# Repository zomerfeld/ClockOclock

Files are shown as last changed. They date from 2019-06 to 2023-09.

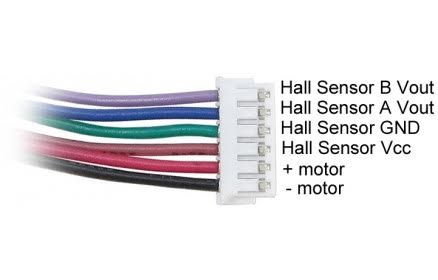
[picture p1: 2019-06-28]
Process_Pics_and_Docs/GearedMotorWiring.jpg

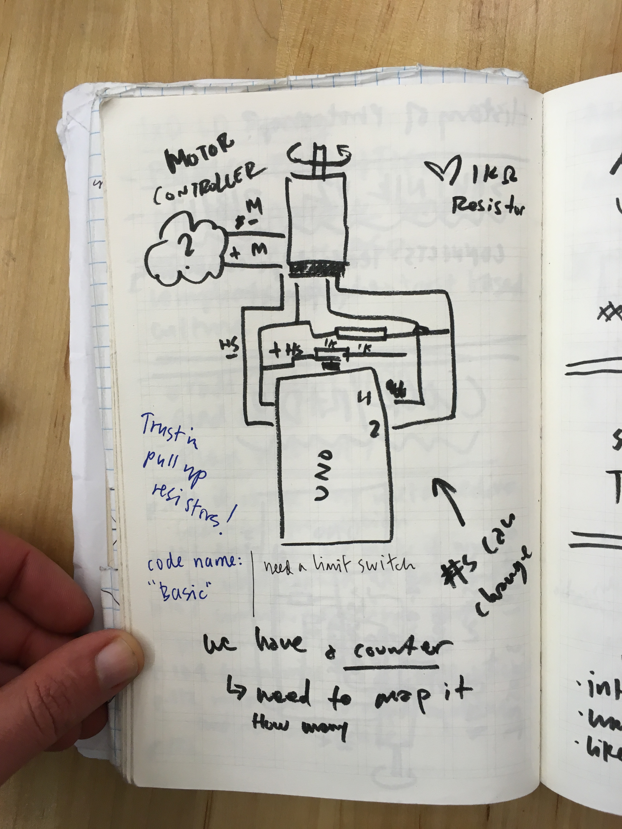
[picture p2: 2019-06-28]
Process_Pics_and_Docs/IMG_1472.JPG

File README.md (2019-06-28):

# ClockOclock
Rachel's Clock Project

## USAGE

### BOOTUP SEQUENCE
* When the radio boots up (or when serial opens) it goes through a calibration sequence:
  * It goes back to try to find the minimum point (it uses magnets and a hall sensor as a limit switch)
  * Then it goes forward to find the max point
  * Then it goes to a predetermined location (currently 90°)
* The board will then map the minimum point to 10 and the max point to 170 (temp values). You can now request it to go to specific angles based on that mapping. 

### MANUAL CONTROL
The board has two physical buttons that will move the motors back and forward. In addition to that, you can also move the dial with the 
* You can also control it via a serial connection, baud rate 250000
#### Commands
* **_\<any number\>_** - after the bootup sequence, this number will work as an angle for the front dial. 
  * Do not put any number lower than 10 or higher than 170 or the motor will try to take it there by force. 
* **_reset_** - runs the calibration sequence again and finds the endges 
* **_f_** - moves the motor forward a bit
* **_b_** - moves the motor backwards a bit

### Alarms
The board is currently set to run two functions on a schedule:
* the function _showTime_ every 5 seconds 
* the function _move90fm_ on a specific time

You can add timers or move the scheduled times under the section "Test Alarms" in the Setup function:
```
  Alarm.alarmRepeat(15, 52, 0, move90fm);
  Alarm.timerRepeat(5, showTime); // show time every 5 seconds

  moveSecAl = Alarm.timerRepeat(6, moveSec); // move every 6 seconds -- disabled currently 
```

## FAQ / TROUBLESHOOTING
#### Wanted ot change the max and min Values?
Change these:
```
int minAngle = 10; // Maximum degree of motion.
int maxAngle = 170; // Maximum degree of motion.
```

## THINGS THAT NEED REWORK
* Mapping isn't accurate (10-170 might need to be adjusted) 
* The board doesn't tell the difference between max and min limit switches currently
* The values for the hall sensor limit switch might need adjusting when you move the radio around to more or less magnetically noise environments.

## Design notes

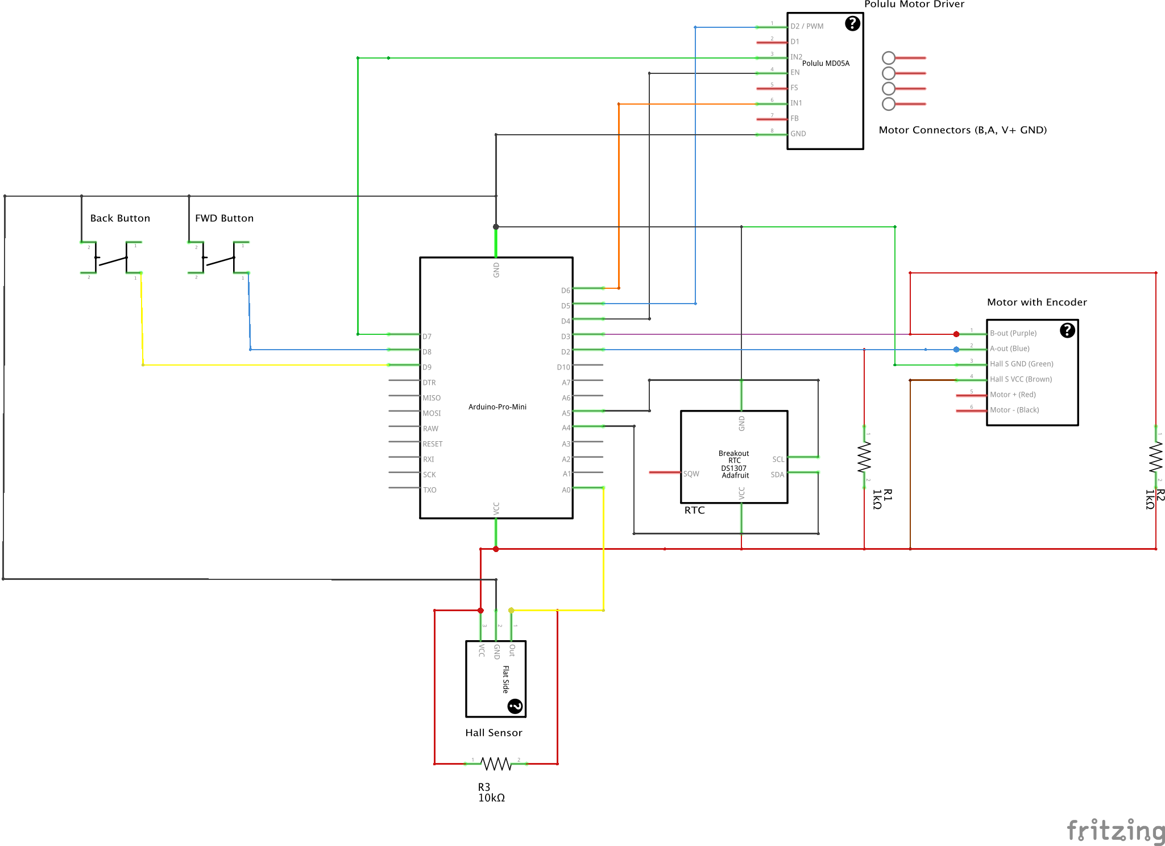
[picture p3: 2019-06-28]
Schematics/clock_oclock_v2_schem.png

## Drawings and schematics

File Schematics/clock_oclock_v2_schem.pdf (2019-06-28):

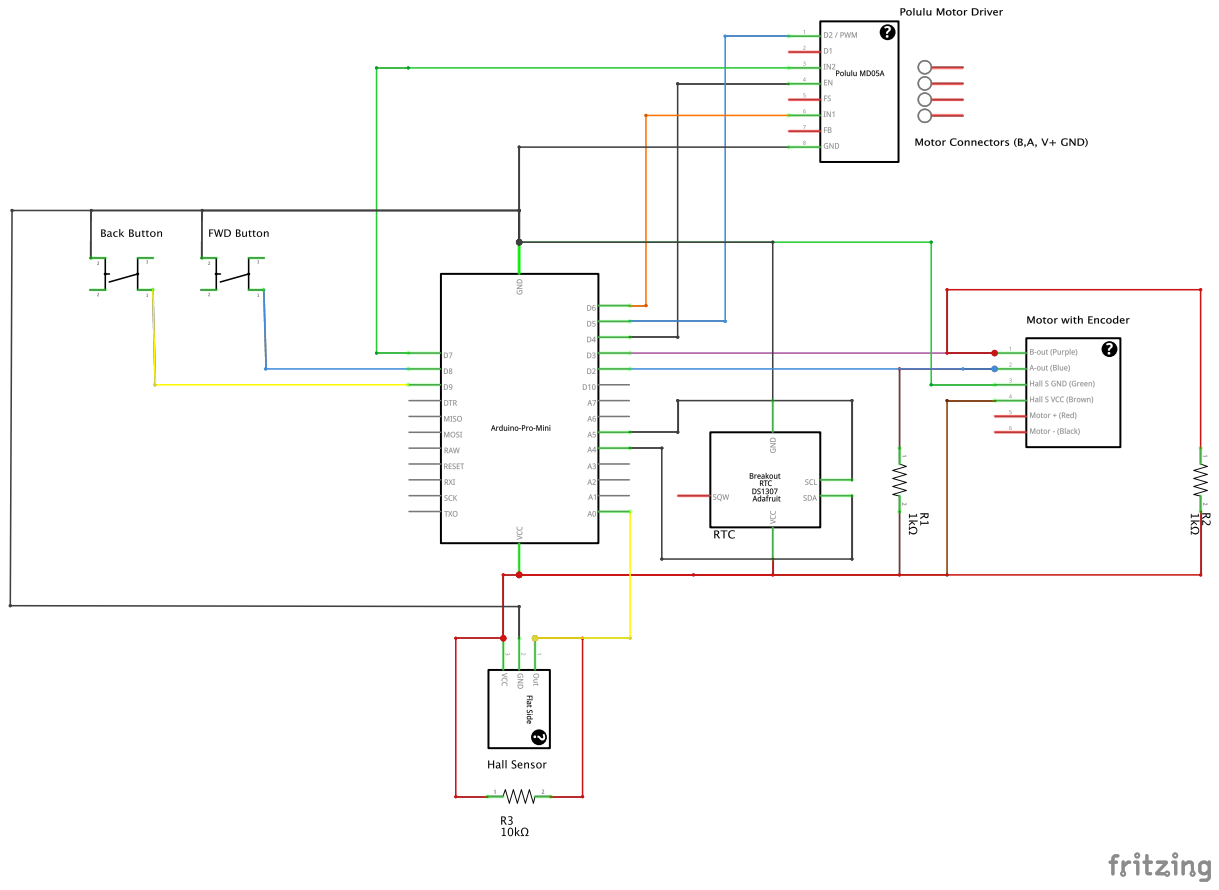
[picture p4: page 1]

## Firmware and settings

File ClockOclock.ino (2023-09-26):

// ***** Timer *****
unsigned long previousMillis = 0;        // will store last time LED was updated
const long printInterval = 5000;           // interval at which to print (milliseconds)


// ***** PID *****
#include <PID_v1.h>

// ***** RTC *****
#include <TimeLib.h>
#include <TimeAlarms.h>
#include <DS1307RTC.h>  // a basic DS1307 library that returns time as a time_t
//#include "RTClib.h"
//RTC_DS1307 rtc;
const char *monthName[12] = {
  "Jan", "Feb", "Mar", "Apr", "May", "Jun",
  "Jul", "Aug", "Sep", "Oct", "Nov", "Dec"
};

tmElements_t tm;


// RTC Wiring: 5V to 5V, GND to GND, SCL to A5 (on Uno, changes by controller), SDA to A4 (on Uno)
// TC Wiring: https://screencast.com/t/50Cv0fAUM7w5

#include <Bounce2.h>
// Initiate a Bounce object: //needed for digital switch
Bounce debouncer1 = Bounce();
Bounce debouncer2 = Bounce();


// *** PID VALUES ***
double kp = 10 , ki = 14 , kd =  0.001;             // modify for optimal performance
double input = 0, output = 0, setpoint = 0;
PID myPID(&input, &output, &setpoint, kp, ki, kd, DIRECT);

// *** MOTOR CONTROL PINS ***
#define enablePin 4 // Connect to EN - Send High or Low to enabled and disable the motor
#define motorSpeedPin 5 // Connect to D2 on the Pololu MD05A (Needs to be PWM pin)
#define CWPin 6 // Connect to IN1 - Turning HIGH will change the motor direction to ClockWise
#define CCWPin 7 // Connect to IN2 - Turning HIGH will change the motor direction to Counter ClockWise
// (flip the A/B wires if the direction is reversed)

#define fwdButton 8 //Button to move motor forward
#define backButton 9 //Button to move motor backward
#define debugLED 13 // Debug LED


// *** LIMIT SWITCH  ***
#define limitSwPin A0 // The pin for the limit switch.  
// For a regular switch, set as INPUT_PULLUP and connect the switch to GND and look for LOW for trigger. (https://www.arduino.cc/en/Tutorial/DigitalInputPullup)
int magnetHigh = 530; // It will only move if between these values!
int magnetLow = 499;


// *** SERIAL VARIABLES ***
String readString; //This while store the user input data
int User_Input = 0; // This while convert input string into integer
boolean stringComplete = false;  // whether the string is complete

// *** CLOCK VARIABLES ***
bool motorDisabled = 0; //To disable the motor passed limits
long maxPosition = 25L * 40000L;
long minPosition = 25L * 40000L;


//long cmdPosition = 200; // Where we're aiming the motor to go
bool motionDone = 1; // If the clock's in motion or not
long distanceMinute = 18; // CHANGE - How much we need to move for one minute passing - in angles
long distance5Second = 5; // CHANGE - How much we need to move for 5 seconds passing - in angles

// *** ENCODER VARIABLES ***
int encoderPin1 = 3; //Encoder Output 'A' must connected with intreput pin of arduino.
int encoderPin2 = 2; //Encoder Otput 'B' must connected with intreput pin of arduino.
//         Best Performance: both pins have interrupt capability
//         Good Performance: only the first pin has interrupt capability
//         Low Performance:  neither pin has interrupt capability
//         Make sure to pull UP those pins up with a 1K resistor (though the code seems to use the INPUT_PULLUP)
volatile int lastEncoded = 0; // Here updated value of encoder store.
volatile long encoderValue = 0; // Raw encoder value
int PPR = 7124;  // Encoder Pulse per revolution.
int minAngle = 12; // degrees to map with magents
int maxAngle = 170; // degrees to map with magnets
int destAngle = 0;
int REV = 0;          // Set point REQUIRED ENCODER VALUE
int lastMSB = 0;
int lastLSB = 0;

int maxGap = 20; // how much tolerance for overshoot or undershoot to say "good enough" and STOP motor. 20 seems a good value.

//these are  storage containers for messaging
long oldPosition  = -999;
long newPosition;


// *** ALARM / SECOND VARIABLES ***
// make this edit to TimeAlarms.h
// #define dtNBR_ALARMS 24  // max is 255
AlarmId id;
bool incrementalToggle = false;

int secondSpeed = 95; //the speed to move when moving once per second
int secondAngle = 1; // the angle-per-move change when moving once a second


// ************************************************************************************************************************************************







// ************************** SETUP **************************

void setup() {

  // ***** STARTS SERIAL & RTC *****
  Serial.begin(250000);
  Serial.println("Rachel's Clock");
  Serial.println("***STARTING RTC***");
  setSyncProvider(RTC.get);   // the function to get the time from the RTC
  setSyncInterval(8000);         // set the number of seconds between re-sync
  readString.reserve(200);   // reserve 200 bytes for the readString

  // *** Set time on RTC ***
  // These lines sets the RTC with an explicit date & time,
//  setTime(23,58,20,9,25,2023); //setTime(hr,min,sec,day,month,yr);
//  RTC.set(now());
  bool parse=false;
  bool config=false;
//
//  // get the date and time the compiler was run
//  if (getDate(__DATE__) && getTime(__TIME__)) {
//    parse = true;
//    // and configure the RTC with this info
//    if (RTC.write(tm)) {
//      config = true;
//    }
//  }


  // ***** PIN SETUP *****
  pinMode(enablePin, OUTPUT);
  pinMode(motorSpeedPin, OUTPUT);
  pinMode(CWPin, OUTPUT);
  pinMode(CCWPin, OUTPUT);
  pinMode(encoderPin1, INPUT_PULLUP);
  pinMode(encoderPin2, INPUT_PULLUP);
  pinMode(limitSwPin, INPUT);
  pinMode(enablePin, OUTPUT);
  pinMode(fwdButton, INPUT_PULLUP);
  pinMode(backButton, INPUT_PULLUP);
  pinMode(debugLED, OUTPUT);

  // encoder parameters
  digitalWrite(encoderPin1, HIGH); //turn pullup resistor on
  digitalWrite(encoderPin2, HIGH); //turn pullup resistor on
  // *** call updateEncoder() when any high/low changed seen
  //     on interrupt 0 (pin 2), or interrupt 1 (pin 3)
  attachInterrupt(0, updateEncoder, CHANGE);
  attachInterrupt(1, updateEncoder, CHANGE);
  REV = map (90, minAngle, maxAngle, minPosition, PPR); // mapping degree into pulse
  setpoint = REV;                    //Destination in revolutions - PID will work to achive this value consider as SET value      REV = map (User_Input, 10, angle, minPosition, PPR); // mapping degree into pulse

  TCCR1B = TCCR1B & 0b11111000 | 1;  // set 31KHz PWM to prevent motor noise

  // *** Setting PID ***
  myPID.SetMode(AUTOMATIC);   //set PID in Auto mode
  myPID.SetSampleTime(1);  // refresh rate of PID controller
  //  myPID.SetOutputLimits(-200, 200); // this is the MAX PWM value to move motor, here change in value reflect change in speed of motor.
  motorSpeed(200); // Sets Motor Speed // 70 is too slow

  // Buttons
  debouncer1.attach(fwdButton);
  debouncer2.attach(backButton);
  debouncer1.interval(90); // 90 seemed to work fast enough. Test and modify if needed
  debouncer2.interval(90); // 90 seemed to work fast enough. Test and modify if needed

  // If using Digital Limit Switch - , setup the Bounce instance (not needed for magnetic limit sw) :
  //  debouncer.attach(limitSwPin);
  //  debouncer.interval(90); // 90 seemed to work fast enough. Test and modify if needed

  // motor settings
  digitalWrite(enablePin, HIGH); // Turns the motor on
  findEdges(); // **** Start the find edges module ****


  // ***** Test Alarms *****
  //  Alarm.alarmRepeat(23,17,0, move90fm);
  //  Alarm.alarmRepeat(23,18,0, move100fm);
  //  Alarm.timerRepeat(5, showTime); // show time every 5 seconds

  //  moveSecAl = Alarm.timerRepeat(6, moveSec); // move every 6 seconds -- disabled currently

  // ****** FM ALARMS ******
  Alarm.alarmRepeat(20, 59, 58, move90fm) ;//should be (20, 59, 58, move90fm);
  Alarm.alarmRepeat(22, 00, 01, move100fm); //should be (22, 00, 01, move100fm)
  Alarm.alarmRepeat(23, 00, 00, moveRest);  //should be (23, 00, 00, moveRest)
  //
  // ****** AM ALARMS ******
  Alarm.alarmRepeat(5, 49, 58, move550am); // Should Be Alarm.alarmRepeat(5, 49, 58, move550am);
  Alarm.alarmRepeat(6, 0 , 0, move600am); // Should Be Alarm.alarmRepeat(6, 0, 0, move600am);
  Alarm.alarmRepeat(7, 0, 0, move700am); // Should Be Alarm.alarmRepeat(7, 0, 0, move700am);
  Alarm.alarmRepeat(8, 0, 0, move800am);  // Should Be Alarm.alarmRepeat(8, 0, 0, move800am);
  Alarm.alarmRepeat(9, 0, 0, move900am);// Should Be Alarm.alarmRepeat(9, 0, 0, move900am);
  Alarm.alarmRepeat(10, 0, 0, move1000am); // Should Be Alarm.alarmRepeat(10, 0, 0, move1000am);
  Alarm.alarmRepeat(11, 0, 0, move1100am); // Should Be Alarm.alarmRepeat(11, 0, 0, move1100am);
  Alarm.alarmRepeat(12, 0, 0, moveRest); // Should Be Alarm.alarmRepeat(12, 0, 0, moveRest);

  // NOT READY THERE MIGHT BE A MAX NUMBER OF ALARMS AND I HAVE TO FIGURE THAT OUT AND RELEASE SOME

}


// **********************************************************





// ************************** LOOP **************************

void loop() {
  // ***** UPDATE TIME *****
  unsigned long currentMillis = millis(); // all time elements are data type unsigned long
  Alarm.delay(0); // Needed to make the time library work.

  // *** Print Time ***
  if ((currentMillis - previousMillis) >= printInterval) { // enough time passed yet?
    previousMillis = currentMillis;
    showTime();
  }

  //  if (incrementalToggle == false) { // decide if to move incrementally (every second) or not
  //    Alarm.disable(moveSecAl);
  //  } else {
  //    Alarm.enable(moveSecAl);
  //  }


  // ***** READ ENCODER *****
  newPosition = encoderValue;
  if (newPosition != oldPosition) {
    oldPosition = newPosition;
    if ((currentMillis - previousMillis) >= printInterval) { // enough time passed yet?
      previousMillis = currentMillis;
      Serial.print ("encoder position: "); // Prints value changes. DEBUG - Disable eventually
      Serial.println(newPosition); // DEBUG - Disable eventually
    }
  }

  //checks the switches
  debouncer1.update(); //checks the switches
  debouncer2.update();

  // ***** MANUAL CONTROL BUTTONS *****

  if (debouncer1.fell()) { //if the button went to low (set to pullup)
    digitalWrite(debugLED, HIGH); //turn on debug led
    Serial.println("moving manually");
    forward();
    analogWrite(motorSpeedPin, 200);
  }

  if (debouncer2.fell()) {
    digitalWrite(debugLED, HIGH); //turn on debug led
    Serial.println("moving manually");
    reverse();
    analogWrite(motorSpeedPin, 200);
  }

  if (debouncer1.rose()) { //when the buttons are not pressed anymore
    Serial.println("Button 1 rose");
    digitalWrite(debugLED, LOW); //turn off debug led
    setpoint = encoderValue;
    stopMotor();
  }

  if (debouncer2.rose()) {
    Serial.println("Button 2 rose");
    digitalWrite(debugLED, LOW); //turn off debug led
    setpoint = encoderValue;
    stopMotor();
  }

  // ********************

  // *** Debug LED for Limit Switches
  if ((analogRead(limitSwPin) >= magnetHigh) || (analogRead(limitSwPin) <= magnetLow)) { // numbers might need adjusting based on analog reads of hall sensor
    digitalWrite(debugLED, HIGH); //turn on debug led
    if ((currentMillis - previousMillis) >= printInterval) { // enough time passed yet?
      previousMillis = currentMillis;
      Serial.print("LIMIT - HALL SENSOR READING: ");
      Serial.println(analogRead(limitSwPin));
    }
  } else {
    digitalWrite(debugLED, LOW); //turn off debug LED
  }

  // **** Serial handling  ****
  if (stringComplete) {
    readString.trim();
    Serial.println(readString);
    if (readString == "b") {
      Serial.println("moving back a bit");
      reverse();
      analogWrite(motorSpeedPin, 150);
      Alarm.delay(250);
      setpoint = encoderValue;
      stopMotor();
      Serial.println("stopped manual move");

    } else if (readString == "f") {
      Serial.println("moving fwd a bit");
      forward();
      analogWrite(motorSpeedPin, 150);
      Alarm.delay(250);
      setpoint = encoderValue;
      stopMotor();
      Serial.println("stopped manual move");
    } else if (readString == "reset") {
      Serial.println("Reset - FindingEdges");
      findEdges();
      clrSrString();
    } else if (readString == "time") {
      showTime();
    } else if (readString == "m90f") {
      Serial.println("moving to 90FM");
      move90fm ();
      clrSrString();
    } else if (readString == "m100f") {
      Serial.println("moving to 100fm");
      move100fm();
      clrSrString();
    } else if (readString == "m550a") {
      move550am ();
      clrSrString();
    } else if (readString == "m600a") {
      move600am ();
      clrSrString();
    } else if (readString == "m700a") {
      move700am ();
      clrSrString();
    } else if (readString == "m800a") {
      move800am ();
      clrSrString();
    } else if (readString == "m900a") {
      move900am ();
      clrSrString();
    } else if (readString == "m1000a") {
      move1000am ();
      clrSrString();
    } else if (readString == "m1100a") {
      move1100am ();
      clrSrString();
    } else if (readString == "rest") {
      moveRest ();
      clrSrString();


    } else {
      Serial.println(readString.toInt());  //printing the input data in integer form
      User_Input = readString.toInt();   // here input data is store in integer form
      if (User_Input < 5) {
        User_Input = 5;
      }
      REV = map (User_Input, minAngle, maxAngle, minPosition, PPR); // mapping degree into pulse
      setpoint = REV;                    //Destination in revolutions - PID will work to achive this value consider as SET value

    }
  }

  input = encoderValue ;           // data from encoder consider as a Process value


  // *** CHECK FOR DESTINATION STOP *** //DOES THIS WORK???? (NZ)
  double gap = abs(setpoint - input); //distance away from setpoint
  if ((digitalRead(fwdButton) == 1) && (digitalRead(backButton) == 1)) {
    if (gap < maxGap) { //we're close to setpoint, stop
      //      if ((currentMillis - previousMillis) >= printInterval) { // enough time passed yet?
      //        previousMillis = currentMillis;
      //        Serial.println("*** CLOSE TO GAP ***"); // DEBUG - Disable eventually
      //        Serial.print("Buttons State ");
      //        Serial.print(digitalRead(fwdButton));
      //        Serial.print("       ");
      //        Serial.println(digitalRead(backButton));
      //    }
      stopMotor();
    }
    else // **** MOVE MOVE MOVE ****
    {
      //we're far from setpoint
      myPID.Compute();                 // calculate new output
      pwmOut(output);
      //      Serial.print("this is REV: ");
      //      Serial.println(REV);
      Serial.print("encoderValue: ");
      Serial.print(encoderValue);
      Serial.print("   (g:");
      Serial.print(gap);
      Serial.println(")");

    }
  }

  // clear the string:
  clrSrString();


  //  // Print the hall sensor reading (Every time? NZ)
  //  if ((currentMillis - previousMillis) >= printInterval) { // enough time passed yet?
  //    previousMillis = currentMillis;
  //    Serial.print("LIMIT - HALL SENSOR READING: ");
  //    Serial.println(analogRead(limitSwPin));
  //  }


} //  *** end of loop ***


//encoder function
void updateEncoder() {
  int MSB = digitalRead(encoderPin1); //MSB = most significant bit
  int LSB = digitalRead(encoderPin2); //LSB = least significant bit

  int encoded = (MSB << 1) | LSB; //converting the 2 pin value to single number
  int sum  = (lastEncoded << 2) | encoded; //adding it to the previous encoded value

  if (sum == 0b1101 || sum == 0b0100 || sum == 0b0010 || sum == 0b1011) encoderValue ++;
  if (sum == 0b1110 || sum == 0b0111 || sum == 0b0001 || sum == 0b1000) encoderValue --;

  lastEncoded = encoded; //store this value for next time

}

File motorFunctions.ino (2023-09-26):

void pwmOut(int out) {
  if (out > 0) {                         // if REV > encoderValue motor move in forward direction.
    analogWrite(motorSpeedPin, out);         // Enabling motor enable pin to reach the desire angle
    forward();                           // calling motor to move forward
    //Serial.print("Moving FWD: ");
    //Serial.println(out);
    //    checkMax(); //stops the motor from moving past the max point.
  }
  else {
    analogWrite(motorSpeedPin, abs(out));          // if REV < encoderValue motor move in forward direction.
    //    Serial.print("Moving BACK: ");
    //    Serial.println(out);
    reverse();                            // calling motor to move reverse

  }
}


void forward () {
  digitalWrite(CWPin, LOW);
  digitalWrite(CCWPin, HIGH);
  //  Serial.println("forward()");
}

void reverse () {
  digitalWrite(CWPin, HIGH);
  digitalWrite(CCWPin, LOW);
}

void finish () {
  digitalWrite(CWPin, LOW);
  digitalWrite(CCWPin, LOW);
}

void stopMotor() {
  //Serial.println("Done Moving");
  analogWrite(motorSpeedPin, 0);
  motionDone = 1;
  //  Serial.println("**STOPPED**");

}

void checkMax() { //stops the motor if it's trying to go over the max position
  if ((encoderValue + 40 >= maxPosition) & (newPosition >= 60))  {
    Serial.println("Reached Max");
    stopMotor();
    motionDone = 1;
    setpoint = 0;

  }
}

void motorSpeed(int reqSpeed) {
  reqSpeed = abs(reqSpeed);
  myPID.SetOutputLimits(-reqSpeed, reqSpeed);
}

void findEdges () {
  //This function finds the edges for the motor movements - Max and Min
  // uses a limit switch (or a hall magnet switch)
  // it will go all the way back, mark the zero point and then all the way forward (find the max point)
  // then it goes to a specific angle between (see setpoint below)
  // this can be triggered manually by putting "reset" into the serial command.

  Serial.println("FINDING EDGES");
  Alarm.delay(3000);
  while ((analogRead(limitSwPin) <= magnetHigh) && (analogRead(limitSwPin) >= magnetLow)) { // numbers might need adjusting based on analog reads of hall sensor

    Serial.println("Running");
    pwmOut(-150);
    Alarm.delay(0);
    Serial.print("Sensor: ");
    Serial.println(analogRead(limitSwPin));
    newPosition = encoderValue;
    if (newPosition != oldPosition) {
      oldPosition = newPosition;
//            Serial.print ("encoder position: "); // DEBUG - Disable eventually
//            Serial.println(newPosition); // DEBUG - Disable eventually
    }
  }

  //Serial.println("*** FOUND MIN EDGE ***"); // DEBUG - Disable eventually
  stopMotor();
//  encoderValue = 500; // writes 500 to the encoder location because the limit switch is installed  a bit too close / early, you can adjust this if zero is not zero degrees on the radio. 
  minPosition = encoderValue;
  Serial.println("Limit Switch Activated - MIN"); // DEBUG
  Serial.print("New Limit: "); // DEBUG
  Serial.println(encoderValue);

  pwmOut(100); // move FWD a bit
  Alarm.delay(2000); //

  while ((analogRead(limitSwPin) <= magnetHigh) && (analogRead(limitSwPin) >= magnetLow)) { // move only when not on limits. Does this even work??? NZ
    // numbers might need adjusting based on analog reads of hall sensor
    pwmOut(150); // move FWD
    Alarm.delay(0);
    Serial.println("FINDING MAX POINT"); // DEBUG - Disable eventually
    newPosition = encoderValue-410;
    if (newPosition != oldPosition) {
      oldPosition = newPosition;
      Serial.print ("encoder position: "); // DEBUG - Disable eventually
      Serial.println(newPosition); // DEBUG - Disable eventually
      Serial.print("FE: LIMIT - HALL SENSOR READING: ");
      Serial.println(analogRead(limitSwPin));

    }
  }

  maxPosition = newPosition + 200; /// writes max position to be current location plus 200 because the limit switch is a bit too close. Change numbers if it's not 180 degress on the clock 
  Serial.println("*** FOUND MAX EDGE ***"); // DEBUG - Disable eventually
  stopMotor();
  Serial.print("MAX Position: ");
  Serial.println(maxPosition); // DEBUG - Disable eventually
  PPR = maxPosition;
  Alarm.delay(3000); // wait 3 seconds
  Serial.println("Moving to minAngle deg");
  REV = map (10, minAngle, maxAngle, minPosition, PPR); // replace first number with destination you want to go after mapping.
  setpoint = REV; //Destination in revolutions - PID will work to achive this value consider as SET value 
  return;

}

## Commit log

2017-06-02 Wiring and library links
2017-06-30 Timer functions
2017-10-09 5 Second Move
    Created function that moves the motor every 5 seconds (timer based, not RTC based)
2017-10-09 Limit Switch to Analog Hall pt 1
    Also implemented a check on movement before 5 second move
2017-10-09 Finding min and max edges
    with magnet sensor (Analog)
2017-10-10 Wiring Diagram for Motor
2017-10-11 New Magnet Hall Ranges
    plus some other fixes with Rachel (10/10)
    [ClockOclock.ino, motorFunctions.ino]
2017-10-16 Manual Buttons
    on pins 8 and 9 using debouncers
2017-10-16 comments for buttons
2018-12-18 December Changes
    * Magnet Low Adjustment for new sensor location
    * Disable repeated debug messaging about limit switches
    * Directions for movement - 1 = CW, 2 = CCW
    * Adjustment in checkStop for overshoot calculations
    * Prints encoder location on each ShowTime Instant
    [ClockOclock.ino, motorFunctions.ino, timeFunctions.ino]
2019-02-02 PID Inclusion
    * Changes how the encoder is read
    * Changes how you map (maps the entire range to 180 degrees).
    * Changes how you send commands over serial (Just send Degree Destination)
    ** Changes some of the parameters names for Serial Connection
    * Moves to the encoder value matching the called out degree / angles.
    * Changes how you stop (uses PID plus you now have a gap value (maxGap).
2019-02-02 MOTOR REVERSE
    + New function for speed setting
    [ClockOclock.ino, motorFunctions.ino]
2019-02-03 Extra Debug for fixing buttons
    [ClockOclock.ino, motorFunctions.ino]
2019-03-30 Fixed manual buttons
    they also now have a little bounce at the end and maybe that's cute?
    [ClockOclock.ino, motorFunctions.ino]
2019-03-31 Fixed dial direction
    * I flipped the motor wires on the driver chip (now it's black, red, input V+, input Gnd)
    * I changed the encoder pins in the code so it's read in the right direction (0 to Positive numbers)
    * some cleanup
    [ClockOclock.ino, motorFunctions.ino]
2019-06-17 Improved Controls
    * Set new serial controls (f, b, and reset)
    * New Angles (10-170
    * New method for going back for find edges (it isn't better)
    [ClockOclock.ino, motorFunctions.ino]
2019-06-28 Test Timed Movement + Bug Fixes
    * Added some test alarms
    * Changed Magnet value
    * Added destAngle to store desired range (need to be implemented everywhere)
    * Added incremental move trigger and parameters
    * changed the leeway for max destination from 200+ to 50+
    * rest at 90 deg.
    * prints max destination (minus leeway)
    * moveSec draft (not Ready)
    * advanced movement function draft in 90fm
    [ClockOclock.ino, motorFunctions.ino, timeFunctions.ino]
2019-11-15 More images about string and wiring
    pics from rachel
2020-02-28 New Edges and New Serial commands
    edges = makes the min point more flexible without changing the magnets
    functions -> serial commands
    move90fm = m90f
    move100fm = m100f
    move550am = m550a
    Move660am =m600a
    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
2021-03-24 Time and Magnet Values
    Hall Sensor - Changed value for MagnetHigh (the low value for the 0 degree)
    Serial - Added a "time" command that shows you the current time (but the encoder values are a bit off in that reading still?
2021-04-28 New Magnet Values - April 21
2021-05-20 FINALLY TIMED ALARMS WORK
    - replaced all delay with Alarm.delay
    - removed the old Simple Timer Library (made the timed alarms not work)
    [ClockOclock.ino, motorFunctions.ino]
2021-07-06 Find Edges Fix & Test Alarms
    * Find Edges now goes to 0 (or configurable angle)
    * Time Alarms test (only 6 work for some reason though)
    * changed the Alarm.Delay(1) to Alarm.Delay(0)
    * Moved time printing to be a millis operation and not an alarm
    [ClockOclock.ino, motorFunctions.ino, timeFunctions.ino]
2023-09-26 A few fixes
    1. adjusted the way the magnets and angles work with the encoder.It's less accurate to actual degrees but more reliable
    2. Set up new locations for the set times.
    3. Added back the time setting functions.
    [ClockOclock.ino, motorFunctions.ino, timeFunctions.ino]
